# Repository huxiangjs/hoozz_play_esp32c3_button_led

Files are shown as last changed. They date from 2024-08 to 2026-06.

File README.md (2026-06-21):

# ESP32-C3 BUTTON LED
A low-cost button LED.

This is a sub-repository, and the main repository is located at [Hoozz Play](https://github.com/huxiangjs/hoozz_play)



## Basic environment
MCU:
```
idf.py --version
ESP-IDF v5.2.1-76-gbf17be96b4-dirty
```
Circuit:
```
Altium Designer 18.1.9
```

## Pull source code
```shell
git clone https://github.com/huxiangjs/hoozz_play_esp32c3_button_led.git
cd hoozz_play_esp32c3_button_led
git submodule update --init --recursive
```

## Compile and burn from source code
```shell
cd MCU/
idf.py build && idf.py flash
```

## You can also directly burn the released bin file

1. Download the latest release zip package from the Releases column
2. Unzip the zip and you will see the following files:
   ```
   $ tree
   .
   |-- bootloader
   |   `-- bootloader.bin
   |-- flash_args
   |-- partition_table
   |   `-- partition-table.bin
   `-- voice_led.bin

   2 directories, 4 files
   ```
3. Open the latest official download tool `flash_download_tool` (official download address: [other-tools](https://www.espressif.com/en/support/download/other-tools))
4. Use the following options: (1) `Chip Type [ESP32-C3]`; (2) `WorkMode [Develop]`; (3) `LoadMode [USB]`;
5. According to the content of the `flash_args` file, configure the burning file, address and flash type. Keep the default selection for places not mentioned, and finally click **Start** to burn

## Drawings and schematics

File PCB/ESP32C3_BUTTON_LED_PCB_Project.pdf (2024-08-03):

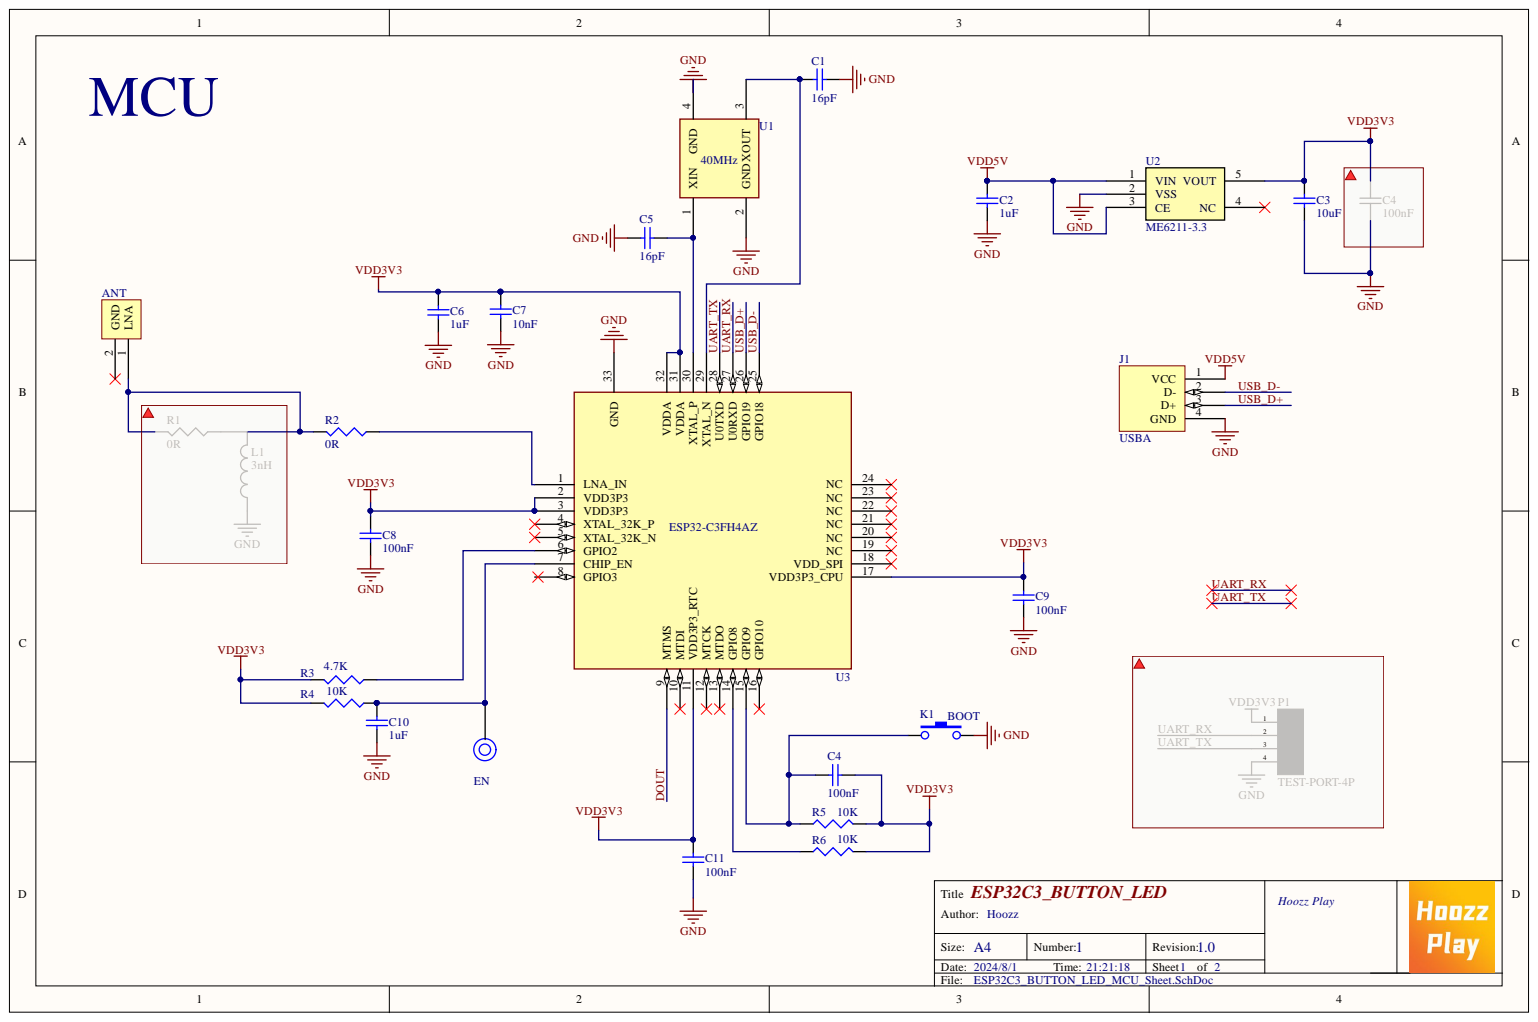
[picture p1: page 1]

ESP32C3_BUTTON_LED Title Author: Hoozz | Hoozz Play

A4 Size: | 1 Number: | 1.0 Revision:
Date: 2024/8/1 Time: 21:21:18 | | Sheet 1 of 2

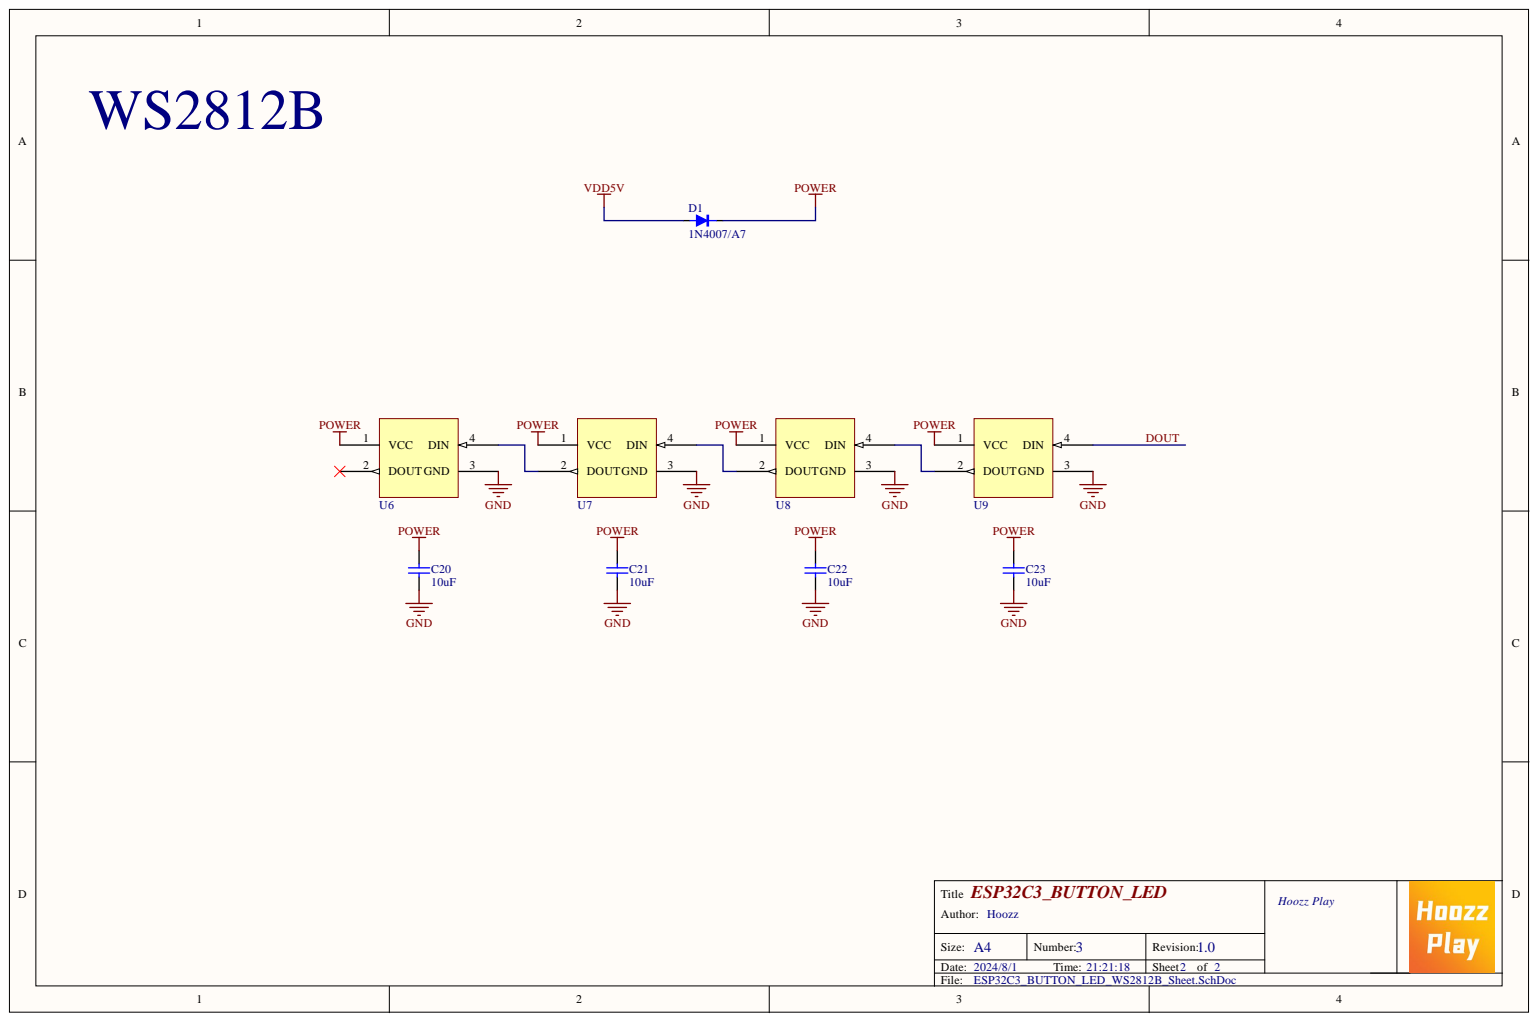
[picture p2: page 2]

ESP32C3_BUTTON_LED Title Author: Hoozz | Hoozz Play

A4 Size: | 3 Number: | 1.0 Revision:
Date: 2024/8/1 Time: 21:21:18 | | Sheet 2 of 2

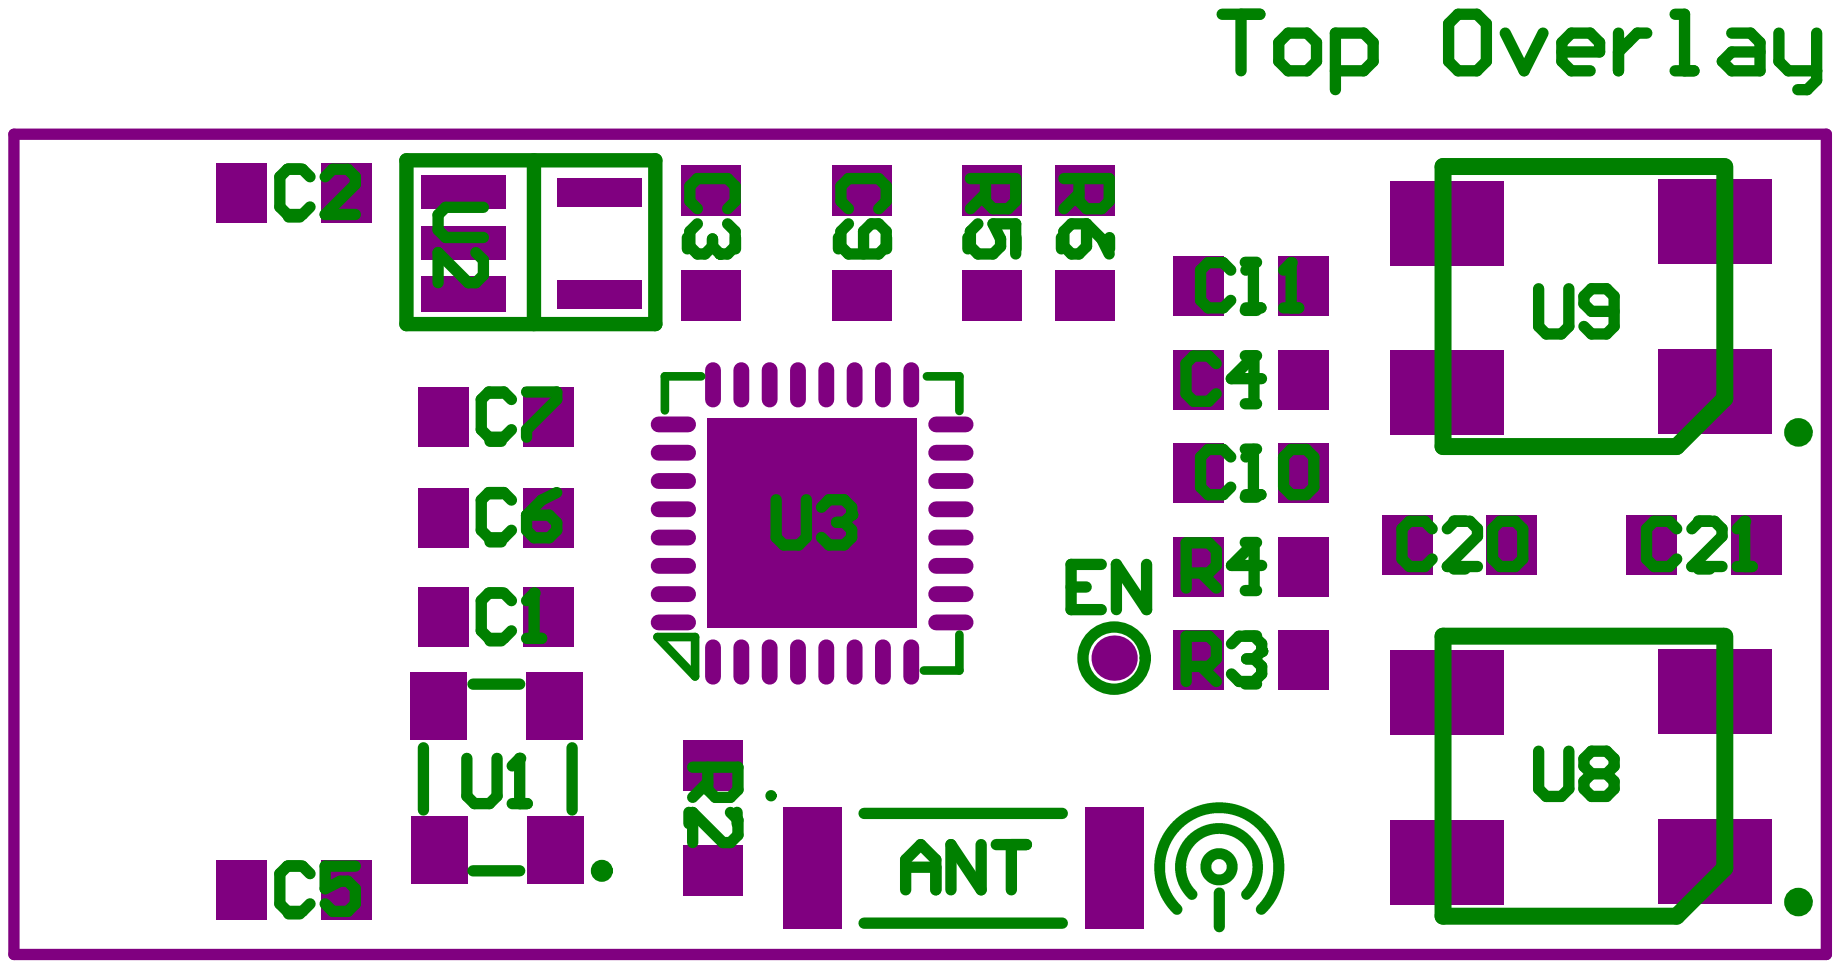
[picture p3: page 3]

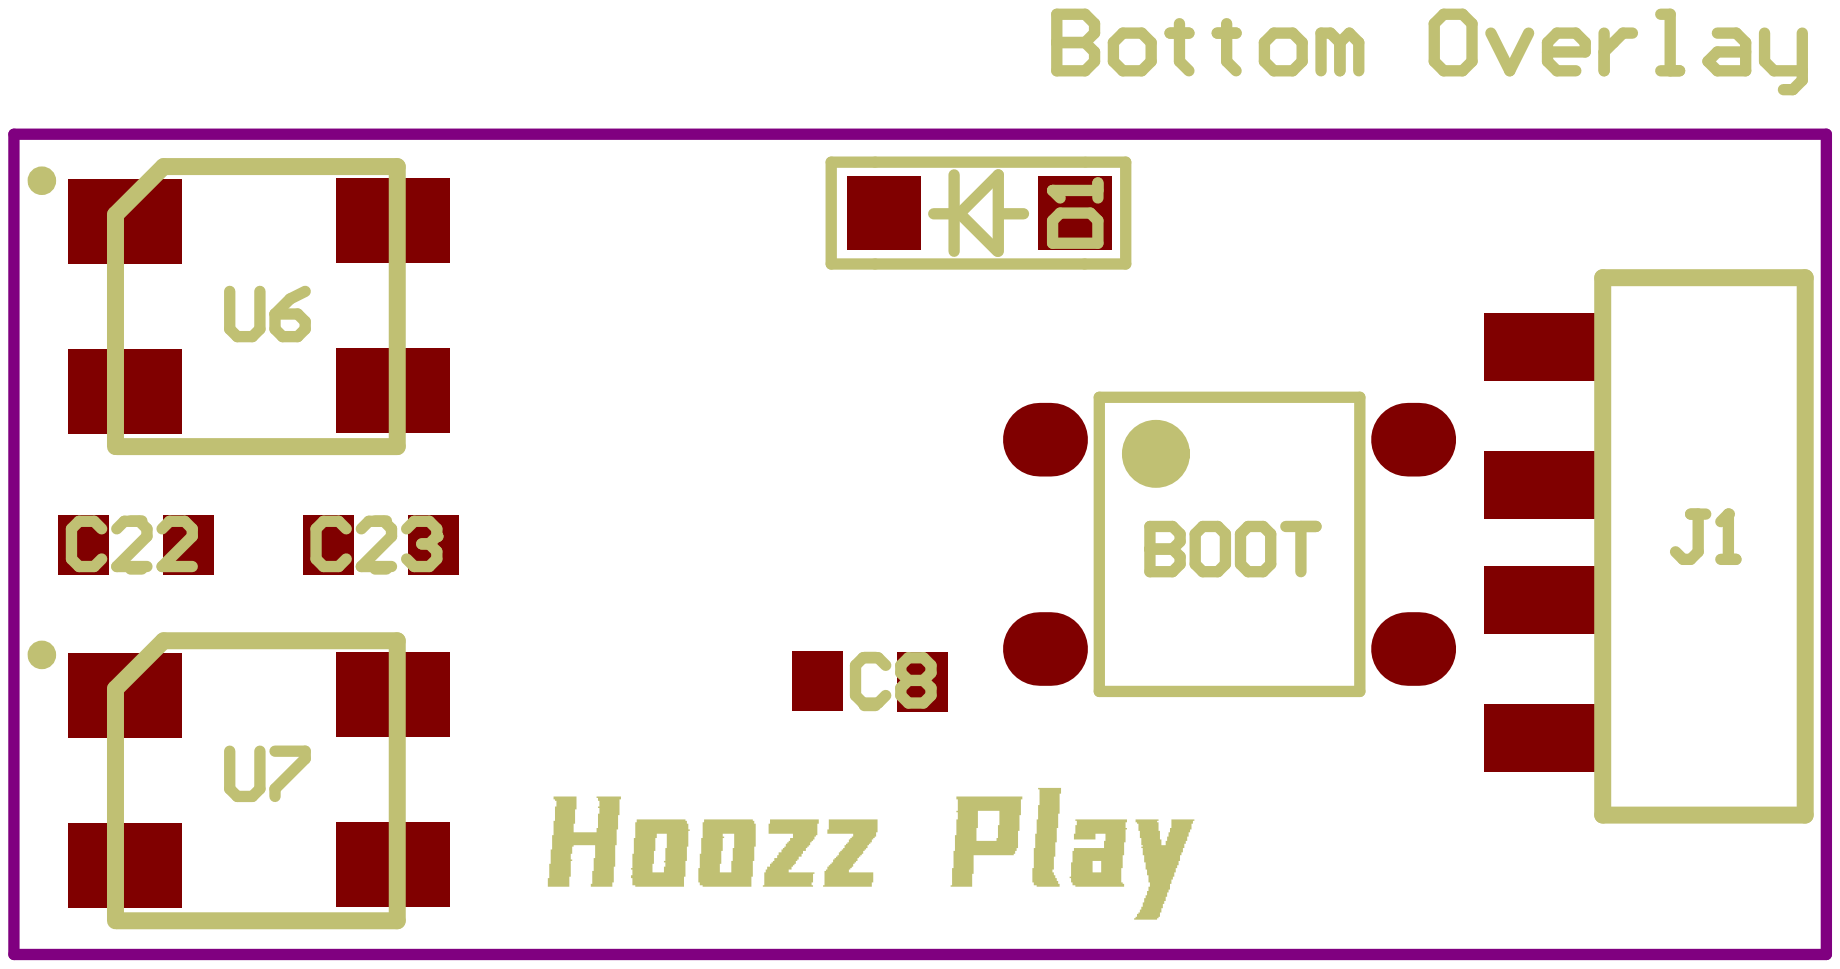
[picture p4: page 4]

Component list | Bill of Materials For Project [ESP32C3_BUTTON_LED_PCB_Project.PrjPCB] (No PCB Document Selected)
Source Data From: | | ESP32C3_BUTTON_LED_PCB_Project.PrjPCB
Project: | | ESP32C3_BUTTON_LED_PCB_Project.PrjPCB
Variant: | | None
Report Date: | 2024/8/1 | 21:21:22
Print Date: | 01-Aug-24 | 9:21:29 PM
# | Designator | Comment | Value | Footprint | Description | Pins | LibRef | Quantity

1 | ANT | ANT | | CA-C03 | | 2 | ANT | 1
2 | C1, C5 | Cap | 16pF | 0603 | Capacitor | 2 | Cap | 2
3 | C2, C6, C10 | Cap | 1uF | 0603 | Capacitor | 2 | Cap | 3
4 | C3, C20, C21, C22, C23 | Cap | 10uF | 0603 | Capacitor | 2 | Cap | 5
5 | C4, C8, C9, C11 | Cap | 100nF | 0603 | Capacitor | 2 | Cap | 4
6 | C7 | Cap | 10nF | 0603 | Capacitor | 2 | Cap | 1
7 | D1 | 1N4007/A7 | | SOD-123FL | | 2 | DIODE | 1
8 | EN | TEST-PORT | | TEST-PORT | | 1 | TEST-PORT | 1
9 | J1 | USBA | | USB-A-2 | USB2.0 | 4 | USBA | 1
10 | K1 | BOOT | | TS-C005 | | 2 | BUTTON | 1
11 | R2 | Res | 0R | 0603 | Resistor | 2 | Res | 1
12 | R3 | Res | 4.7K | 0603 | Resistor | 2 | Res | 1
13 | R4, R5, R6 | Res | 10K | 0603 | Resistor | 2 | Res | 3
14 | U1 | 40MHz | | 3225 | | 4 | XTAL2 | 1
15 | U2 | ME6211-3.3 | | SOT-23-5 | No Description Available | 5 | ME6211-3.3 | 1
16 | U3 | ESP32-C3FH4AZ | | QFN32_3.7X3.7 | | 33 | ESP32-C3FH4AZ | 1
17 | U6, U7, U8, U9 | WS2812B | | 5050 | | 4 | WS2812B | 4
Approved | | | | Notes | | | | 32

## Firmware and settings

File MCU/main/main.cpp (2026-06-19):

/*
 * MIT License
 *
 * Copyright (c) 2024 huxiangjs
 *
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
 * THE SOFTWARE IS PROVIDED "AS IS", WITHOUT WARRANTY OF ANY KIND, EXPRESS OR
 * IMPLIED, INCLUDING BUT NOT LIMITED TO THE WARRANTIES OF MERCHANTABILITY,
 * FITNESS FOR A PARTICULAR PURPOSE AND NONINFRINGEMENT. IN NO EVENT SHALL THE
 * AUTHORS OR COPYRIGHT HOLDERS BE LIABLE FOR ANY CLAIM, DAMAGES OR OTHER
 * LIABILITY, WHETHER IN AN ACTION OF CONTRACT, TORT OR OTHERWISE, ARISING FROM,
 * OUT OF OR IN CONNECTION WITH THE SOFTWARE OR THE USE OR OTHER DEALINGS IN THE
 * SOFTWARE.
 */

#include <stdio.h>
#include <string.h>
#include <sys/unistd.h>
#include <sys/stat.h>
#include "esp_err.h"
#include "esp_log.h"
#include "esp_system.h"
#include "freertos/FreeRTOS.h"
#include "freertos/task.h"
#include "nvs_flash.h"

#include "ws2812b.h"
#include "led_effects.h"
#include "wifi.h"
#include "event_bus.h"
#include "simple_ctrl.h"
#include "store.h"
#include "keyboard.h"

static const char *TAG = "APP-MAIN";

static uint32_t last_color;

#define LED_CMD_SET_COLOR		0x00
#define LED_CMD_GET_COLOR		0x01

#define LED_RESULT_OK			0x00
#define LED_RESULT_FAIL			0x01

#define KEYBOARD_GPIO_PIN		GPIO_NUM_9

static bool led_on;
static bool config_mode;

static void app_show_info(void)
{
	int size = esp_get_free_heap_size();

	ESP_LOGI(TAG, "Free heap size: %dbytes", size);
}

static int app_led_request(char *buffer, int buf_offs, int vaild_size, int buff_size)
{
	uint32_t rgb = 0;

	if (vaild_size < 1) {
		ESP_LOGE(TAG, "Information command is incorrect");
		return -1;
	}

	if (buff_size - buf_offs < 5) {
		ESP_LOGE(TAG, "Not enough buffer space");
		return -1;
	}

	if (buffer[buf_offs] == LED_CMD_SET_COLOR && vaild_size == 4) {
		/* Set color */
		rgb |= buffer[buf_offs + 1] << 0;
		rgb |= buffer[buf_offs + 2] << 8;
		rgb |= buffer[buf_offs + 3] << 16;
		// led_effects_play(LED_EFFECTS_COLOR_FILL, rgb);
		led_effects_play(LED_EFFECTS_COLOR_GRADIENT, rgb);
		ESP_LOGI(TAG, "Set color: #%06x", (unsigned int)rgb);
		/* Set return (2byte) */
		buffer[buf_offs + 1] = LED_RESULT_OK;
		led_on = (bool)!!rgb;
		return 2;
	} else if (buffer[buf_offs] == LED_CMD_GET_COLOR && vaild_size == 1) {
		ESP_LOGI(TAG, "Get color: #%06x", (unsigned int)last_color);
		/* Set return (5byte) */
		buffer[buf_offs + 1] = LED_RESULT_OK;
		buffer[buf_offs + 2] = (uint8_t)((last_color >> 0) & 0xff);
		buffer[buf_offs + 3] = (uint8_t)((last_color >> 8) & 0xff);
		buffer[buf_offs + 4] = (uint8_t)((last_color >> 16) & 0xff);
		return 5;
	} else {
		ESP_LOGE(TAG, "Lllegal command");
		return -1;
	}

	return 0;
}

static void app_led_notify(uint32_t color)
{
	char rgb[3];

	last_color = color;

	rgb[0] = (uint8_t)((color >> 0) & 0xff);
	rgb[1] = (uint8_t)((color >> 8) & 0xff);
	rgb[2] = (uint8_t)((color >> 16) & 0xff);

	simple_ctrl_notify(rgb, sizeof(rgb));
}

static bool app_event_notify_callback(struct event_bus_msg *msg)
{
	switch (msg->type) {
	case EVENT_BUS_STARTUP:
		break;
	case EVENT_BUS_START_SMART_CONFIG:
		break;
	case EVENT_BUS_STOP_SMART_CONFIG:
		config_mode = false;
		break;
	case EVENT_BUS_KEYBOARD:
		if (config_mode || msg->param1 != KEYBOARD_GPIO_PIN)
			break;
		if ((msg->param2 == KEYBOARD_EVENT_SHORT_RELEASE)) {
			if (led_on == false) {
				/* Turn on */
				led_on = true;
				led_effects_play(LED_EFFECTS_ALL_ON, 0);
				ESP_LOGI(TAG, "Turn on");
			} else {
				/* Turn off */
				led_on = false;
				led_effects_play(LED_EFFECTS_ALL_OFF, 0);
				ESP_LOGI(TAG, "Turn off");
			}
		}
		/* Smart config */
		if (msg->param2 == KEYBOARD_EVENT_LONG_RELEASE) {
			ESP_LOGI(TAG, "Smart config");
			wifi_smartconfig();
			led_on = false;
			config_mode = true;
		}
		break;
	case EVENT_BUS_LED_COLOR_UPDATED:
		ESP_LOGD(TAG, "Color updated");
		app_led_notify(msg->param1);
		break;
	}

	return false;
}

extern "C" void app_main(void)
{
	struct event_bus_msg msg = { EVENT_BUS_STARTUP, 0, 0};
	uint8_t keyboard_gpios[] = { KEYBOARD_GPIO_PIN };

	app_show_info();
	ESP_ERROR_CHECK(nvs_flash_init());

	store_init();

	/* Event bus */
	event_bus_init();
	event_bus_register(app_event_notify_callback);
	event_bus_send(&msg);

	/* LED */
	led_effects_init();

	/* KEYBOARD */
	keyboard_init(keyboard_gpios, sizeof(keyboard_gpios));

	/* Wifi */
	wifi_init();

	/* Network ctrl */
	simple_ctrl_init();
	simple_ctrl_set_name("BUTTON LED");
	simple_ctrl_set_class_id(CLASS_ID_BUTTON_LED);
	simple_ctrl_request_register(app_led_request);
	wifi_connect();

	app_show_info();
}

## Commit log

2024-08-03 Add MCU code
    [partitions.csv]
2024-08-03 Add PCB product files
    [ESP32C3_BUTTON_LED_MCU_Sheet.SchDoc, ESP32C3_BUTTON_LED_PCB.PcbDoc, ESP32C3_BUTTON_LED_PCB_Project.PrjPCB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]
2024-08-04 Change device type and optimize code
2026-06-21 Update ESP32 workflow configuration
2026-06-21 Enhance GitHub Actions workflow for ESP32
    Added steps to install jq, check for tag pushes, create a release, and upload the release asset.
2026-06-21 Add CI badge to README for ESP32
    Added CI badge for ESP32 workflow.
